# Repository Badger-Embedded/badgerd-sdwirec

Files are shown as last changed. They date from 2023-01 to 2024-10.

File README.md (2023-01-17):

# Badgerd SDWireC
[SDWireC](https://badgerd.nl/sdwirec) is a yet another implementation of SDWire of Tizen. In our design we used USB-C interface to interact with the host device or in other words Test Server(TS).

In **sdwirec-hw** folder, you can find the KiCAD project files of SDWireC, hardware design mostly based on Tizen but we changed some of the components since they are out of stock today.

In **sdwirec-sw** folder, you will find the clone of https://git.tizen.org/cgit/tools/testlab/sd-mux which has the software that you need to interact with SDWireC.

## Please follow the instructions in [Quick Start Guide](https://badgerd.nl/sdwirec/#quick-start) to give SDWireC a kickstart!

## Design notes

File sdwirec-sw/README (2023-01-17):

sd-mux stands for Secure Digital Multiplexer.

This is SD card switcher (multiplexer) designed to help automatic testing.

This project is sd-mux controller - binary for controlling sd-mux device.

Requirements:
  1. libftdi1 1.4 - development library
  2. popt - development library
  3. cmake - binary tool

Build:
 - enter into project directory
 - create 'build' directory
 - enter into "build" directory
 - run 'cmake ..'
 - run 'make'

Install:
 - enter into 'build' directory
 - run 'sudo make install' to install binary into '/usr/local/bin' (the default one) directory

Note:
If you want to install files into different directory then add argument to cmake command:
 cmake -DCMAKE_INSTALL_PREFIX=/usr ..
Then again run:
 make
 make install

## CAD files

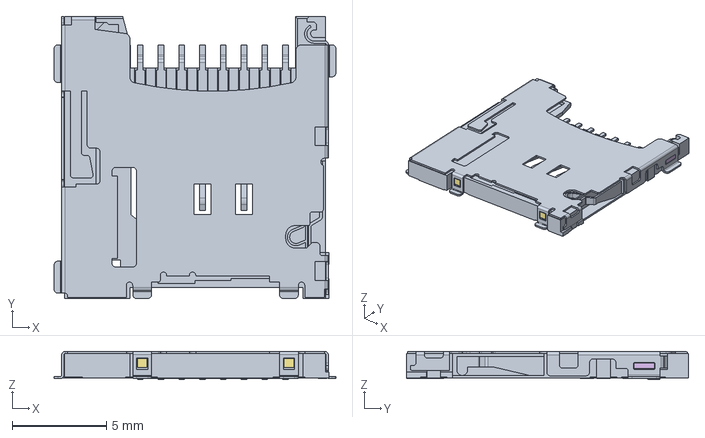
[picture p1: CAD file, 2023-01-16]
sdwirec-hw/components/503182-1852.stp
14.9 x 14.9 x 1.50 mm

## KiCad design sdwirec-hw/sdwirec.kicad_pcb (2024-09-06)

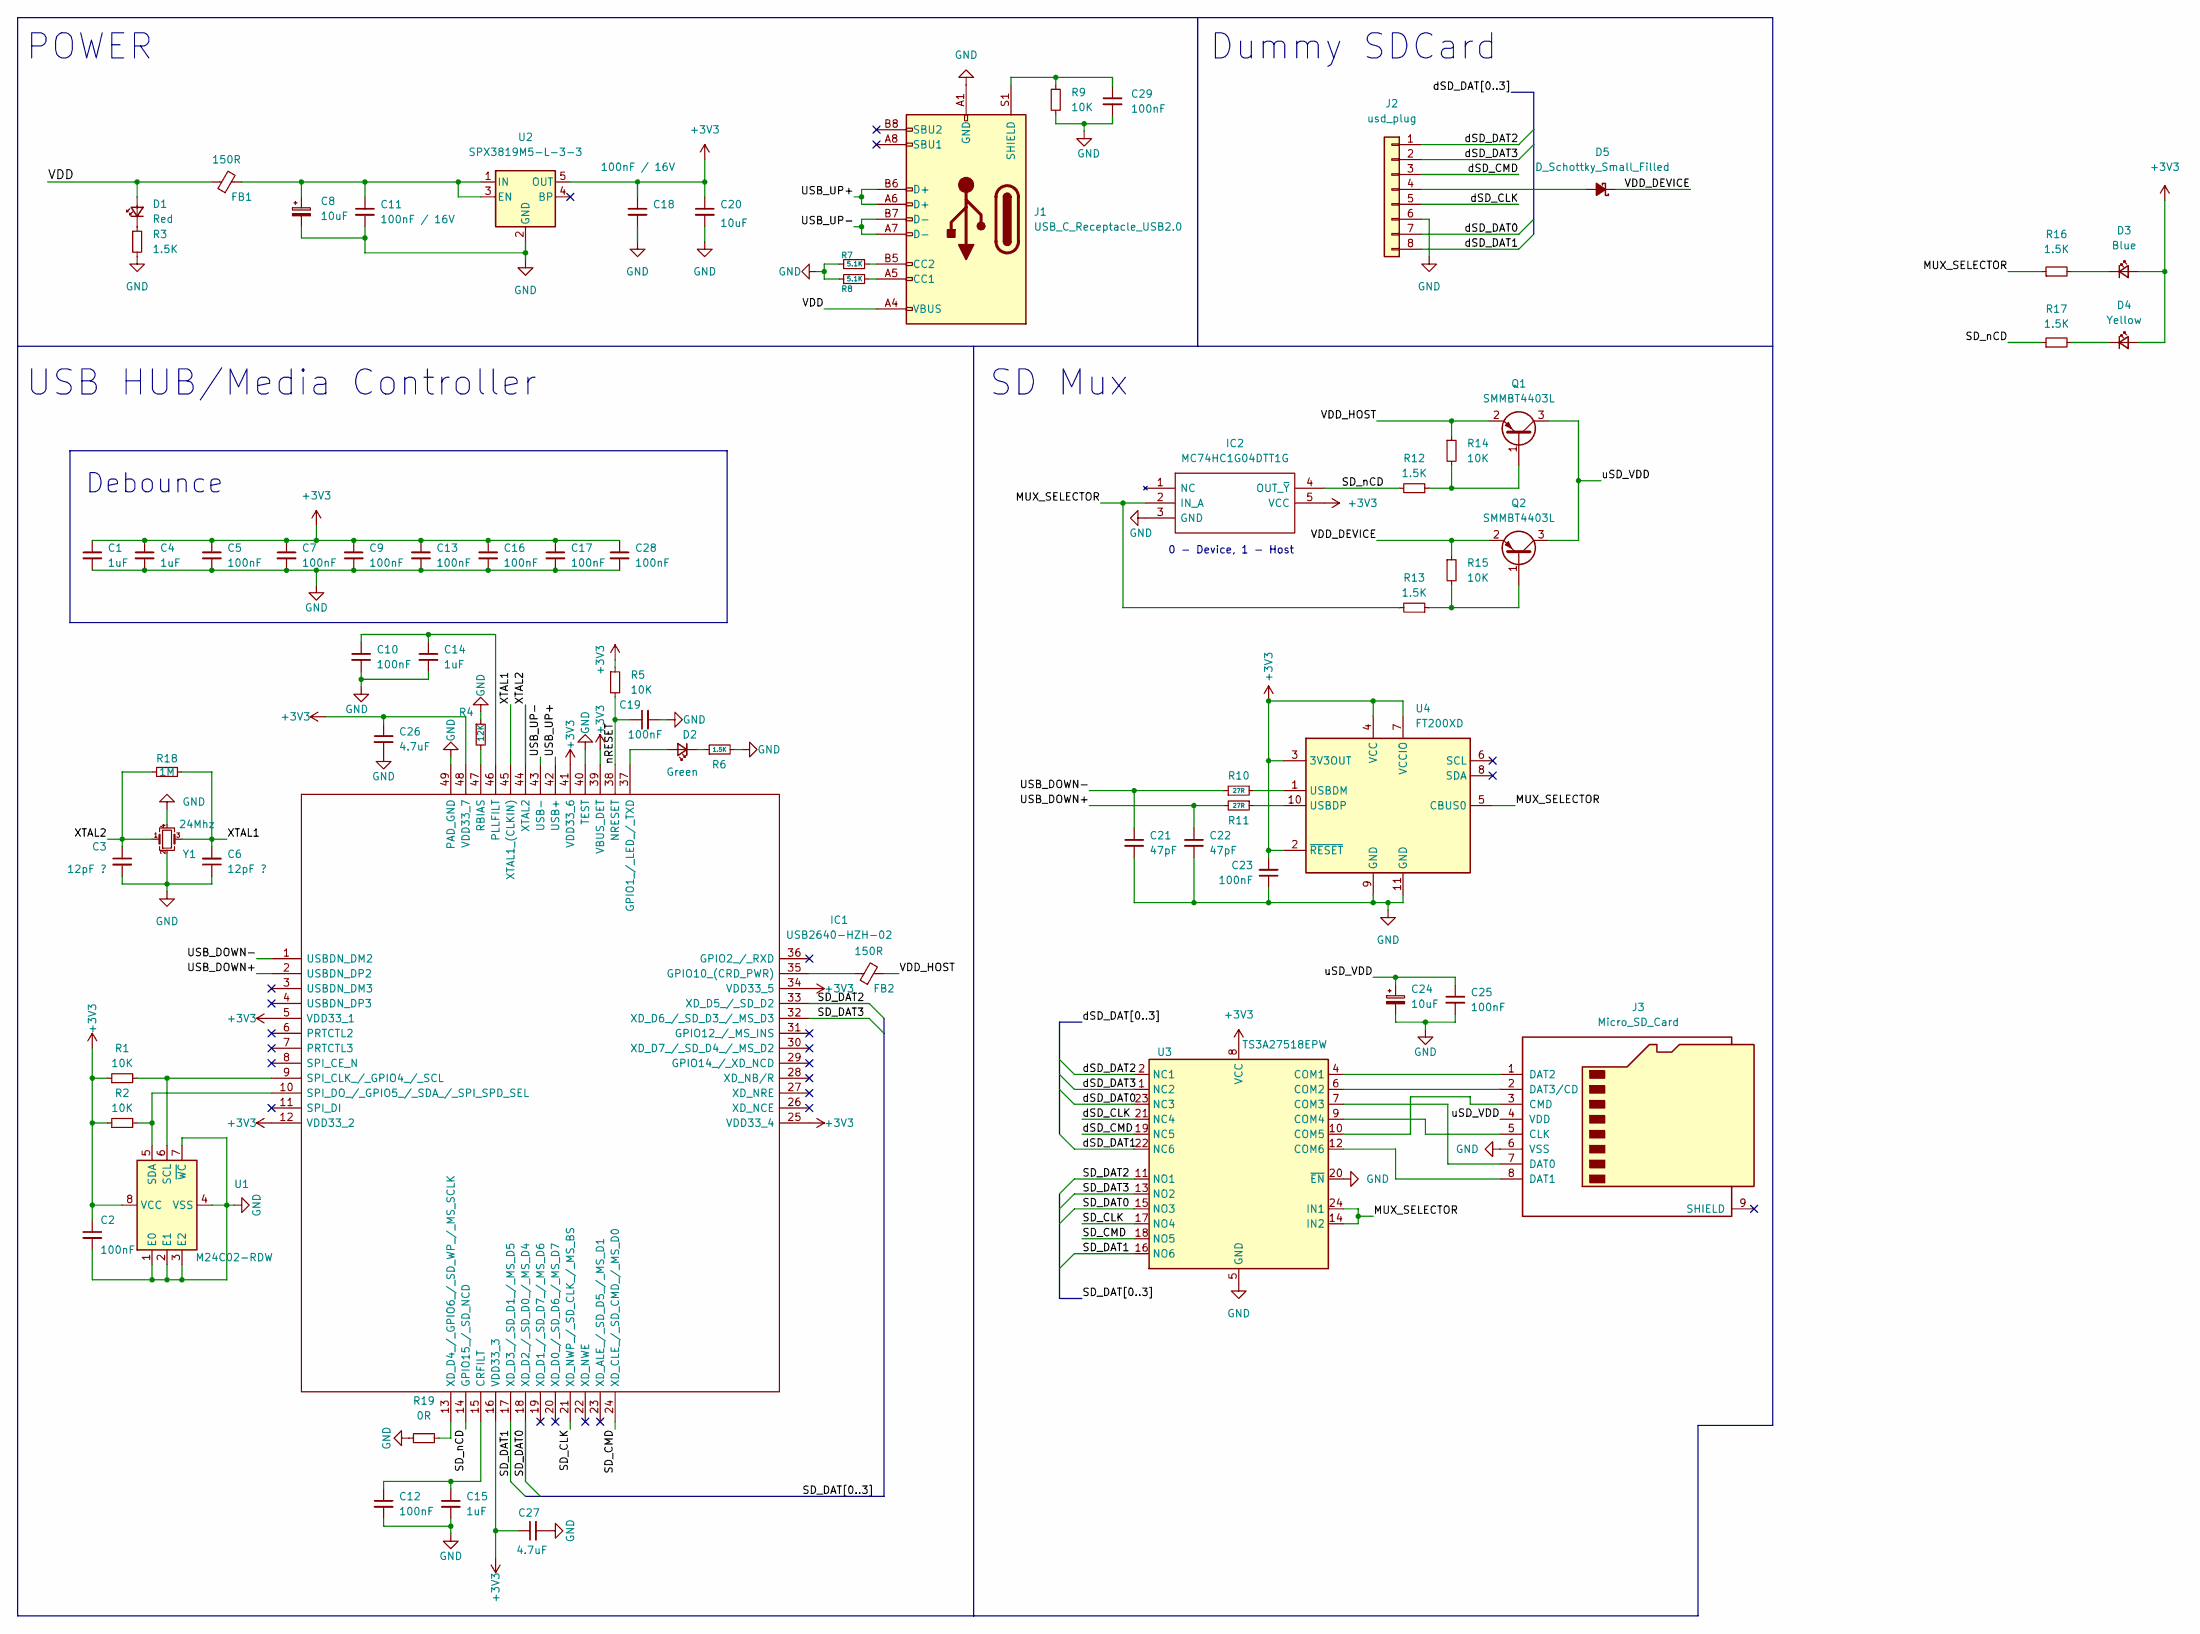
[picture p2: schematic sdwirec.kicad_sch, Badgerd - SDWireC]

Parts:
C1, C4, C14, C15: 1uF; C_0603_1608Metric; JLC 0603
C2, C5, C7, C9, C10, C12, C13, C16, C17, C19, C23, C25, C28: 100nF; C_0402_1005Metric; JLC 0402
C3, C6: 12pF ?; C_0402_1005Metric; JLC 0402
C8, C24: 10uF; CP_EIA-3216-18_Kemet-A; JLC CASE-A-3216
C11, C18: 100nF / 16V; C_0402_1005Metric; JLC 0402
C20: 10uF; C_0603_1608Metric; JLC 0603
C21, C22: 47pF; C_0402_1005Metric; JLC 0402
C26, C27: 4.7uF; C_0603_1608Metric; JLC 0603
C29: 100nF; C_0402_1005Metric
D1: Red; LED_0402_1005Metric; JLC 0402
D2: Green; LED_0402_1005Metric; JLC 0402
D3: Blue; LED_0402_1005Metric; JLC 0402
D4: Yellow; LED_0402_1005Metric; JLC 0402
D5: D_Schottky_Small_Filled; D_0402_1005Metric; LCSC Part C2837790
FB1, FB2: 150R; D_0603_1608Metric; JLC 0603
IC1: USB2640-HZH-02; QFN50P700X700X100-49N-D; Mouser Part Number 886-USB2640-HZH-02
IC2: MC74HC1G04DTT1G; SOT95P275X110-5N; Mouser Part Number 863-MC74HC1G04DTT1G
J1: USB_C_Receptacle_USB2.0; USB_C_Receptacle_GCT_USB4105-xx-A_16P_TopMnt_Horizontal; JLC SMD
J2: usd_plug; usd
J3: Micro_SD_Card; 5031821852; LCSC Part C587953
Q1, Q2: SMMBT4403L; SOT-23-3; JLC SOT-23-3
R1, R2, R5, R9, R14, R15: 10K; R_0402_1005Metric; JLC 0402
R3, R6, R12, R13, R16, R17: 1.5K; R_0402_1005Metric; JLC 0402
R4: 12K; R_0402_1005Metric; JLC 0402
R7, R8: 5.1K; R_0402_1005Metric; LCSC Part C25905
R10, R11: 27R; R_0402_1005Metric; JLC 0402
R18: 1M; R_0402_1005Metric
R19: 0R; R_0402_1005Metric; JLC 0402
U1: M24C02-RDW; TSSOP-8_4.4x3mm_P0.65mm; JLC TSSOP-8-3.0mm
U2: SPX3819M5-L-3-3; SOT-23-5; JLC SOT-23-5
U3: TS3A27518EPW; TSSOP-24_4.4x7.8mm_P0.65mm; JLC TSSOP-24
U4: FT200XD; DFN-10-1EP_3x3mm_P0.5mm_EP1.55x2.48mm; JLC DFN-10-EP(3x3)
Y1: 24Mhz; Crystal_SMD_3225-4Pin_3.2x2.5mm; JLC SMD3225-4P

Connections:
+3V3: C1.1, C2.1, C4.1, C5.1, C7.1, C9.1, C13.1, C16.1, C17.1, C18.1, C20.1, C23.2, C26.1, C27.1, C28.1, D3.2 (A), D4.2 (A), IC1.5 (VDD33_1), IC1.12 (VDD33_2), IC1.16 (VDD33_3), IC1.25 (VDD33_4), IC1.34 (VDD33_5), IC1.39 (VBUS_DET), IC1.41 (VDD33_6), IC1.48 (VDD33_7), IC2.5 (VCC), R1.1, R2.1, R5.1, U1.8 (VCC), U2.5 (OUT), U3.8 (VCC), U4.2 (~RESET), U4.3 (3V3OUT), U4.4 (VCC), U4.7 (VCCIO)
/MUX_SELECTOR: IC2.2 (IN_A), R13.2, R16.1, U3.14 (IN2), U3.24 (IN1), U4.5 (CBUS0)
/SD_CLK: IC1.21 (XD_NWP_/_SD_CLK_/_MS_BS), U3.17 (NO4)
/SD_CMD: IC1.24 (XD_CLE_/_SD_CMD_/_MS_D0), U3.18 (NO5)
/SD_DAT0: IC1.18 (XD_D2_/_SD_D0_/_MS_D4), U3.15 (NO3)
/SD_DAT1: IC1.17 (XD_D3_/_SD_D1_/_MS_D5), U3.16 (NO6)
/SD_DAT2: IC1.33 (XD_D5_/_SD_D2), U3.11 (NO1)
/SD_DAT3: IC1.32 (XD_D6_/_SD_D3_/_MS_D3), U3.13 (NO2)
/SD_nCD: IC1.14 (GPIO15_/_SD_NCD), IC2.4 (OUT_~Y), R12.2, R17.1
/USB_DOWN+: C22.1, IC1.2 (USBDN_DP2), R11.2
/USB_DOWN-: C21.1, IC1.1 (USBDN_DM2), R10.1
/USB_UP+: IC1.42 (USB+), J1.A6 (D+), J1.B6 (D+)
/USB_UP-: IC1.43 (USB-), J1.A7 (D-), J1.B7 (D-)
/VDD: D1.2 (A), FB1.1, J1.A4 (VBUS), J1.A9 (VBUS), J1.B4 (VBUS), J1.B9 (VBUS)
/VDD_DEVICE: D5.1 (K), Q2.2 (E), R15.1
/VDD_HOST: FB2.2, Q1.2 (E), R14.1
/XTAL1: C6.2, IC1.45 (XTAL1_(CLKIN)), R18.2, Y1.3
/XTAL2: C3.1, IC1.44 (XTAL2), R18.1, Y1.1
/dSD_CLK: J2.5, U3.21 (NC4)
/dSD_CMD: J2.3, U3.19 (NC5)
/dSD_DAT0: J2.7, U3.23 (NC3)
/dSD_DAT1: J2.8, U3.22 (NC6)
/dSD_DAT2: J2.1, U3.2 (NC1)
/dSD_DAT3: J2.2, U3.1 (NC2)
/nRESET: C19.1, IC1.38 (NRESET), R5.2
/uSD_VDD: C24.1, C25.1, J3.4 (VDD), Q1.3 (C), Q2.3 (C)
GND: C1.2, C2.2, C3.2, C4.2, C5.2, C6.1, C7.2, C8.2, C9.2, C10.2, C11.2, C12.2, C13.2, C14.2, C15.2, C16.2, C17.2, C18.2, C19.2, C20.2, C21.2, C22.2, C23.1, C24.2, C25.2, C26.2, C27.2, C28.2, C29.2, IC1.40 (TEST), IC1.49 (PAD_GND), IC2.3 (GND), J1.A1 (GND), J1.A12 (GND), J1.B1 (GND), J1.B12 (GND), J2.6, J3.6 (VSS), R3.2, R4.1, R6.2, R7.1, R8.1, R9.2, R19.1, U1.1 (E0), U1.2 (E1), U1.3 (E2), U1.4 (VSS), U1.7 (~WC), U2.2 (GND), U3.5 (GND), U3.20 (~EN), U4.9 (GND), U4.11 (GND), Y1.2, Y1.4
unnamed: C10.1, C14.1, IC1.46 (PLLFILT)
unnamed: C8.1, C11.1, FB1.2, U2.1 (IN), U2.3 (EN)
unnamed: C12.1, C15.1, IC1.15 (CRFILT)
unnamed: C29.1, J1.S1 (SHIELD), R9.1
unnamed: D1.1 (K), R3.1
unnamed: D2.1 (K), R6.1
unnamed: D2.2 (A), IC1.37 (GPIO1_/_LED_/_TXD)
unnamed: D3.1 (K), R16.2
unnamed: D4.1 (K), R17.2
unnamed: FB2.1, IC1.35 (GPIO10_(CRD_PWR))
unnamed: IC1.9 (SPI_CLK_/_GPIO4_/_SCL), R1.2, U1.6 (SCL)
unnamed: IC1.10 (SPI_DO_/_GPIO5_/_SDA_/_SPI_SPD_SEL), R2.2, U1.5 (SDA)
unnamed: IC1.13 (XD_D4_/_GPIO6_/_SD_WP_/_MS_SCLK), R19.2
unnamed: IC1.47 (RBIAS), R4.2
unnamed: J1.A5 (CC1), R8.2
unnamed: J1.B5 (CC2), R7.2
unnamed: D5.2 (A), J2.4
unnamed: J3.1 (DAT2), U3.4 (COM1)
unnamed: J3.2 (DAT3/CD), U3.6 (COM2)
unnamed: J3.3 (CMD), U3.10 (COM5)
unnamed: J3.5 (CLK), U3.9 (COM4)
unnamed: J3.7 (DAT0), U3.7 (COM3)
unnamed: J3.8 (DAT1), U3.12 (COM6)
unnamed: Q1.1 (B), R12.1, R14.2
unnamed: Q2.1 (B), R13.1, R15.2
unnamed: R10.2, U4.1 (USBDM)
unnamed: R11.1, U4.10 (USBDP)

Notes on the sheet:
0 - Device, 1 - Host
POWER
SD Mux
USB HUB/Media Controller
Dummy SDCard
Debounce

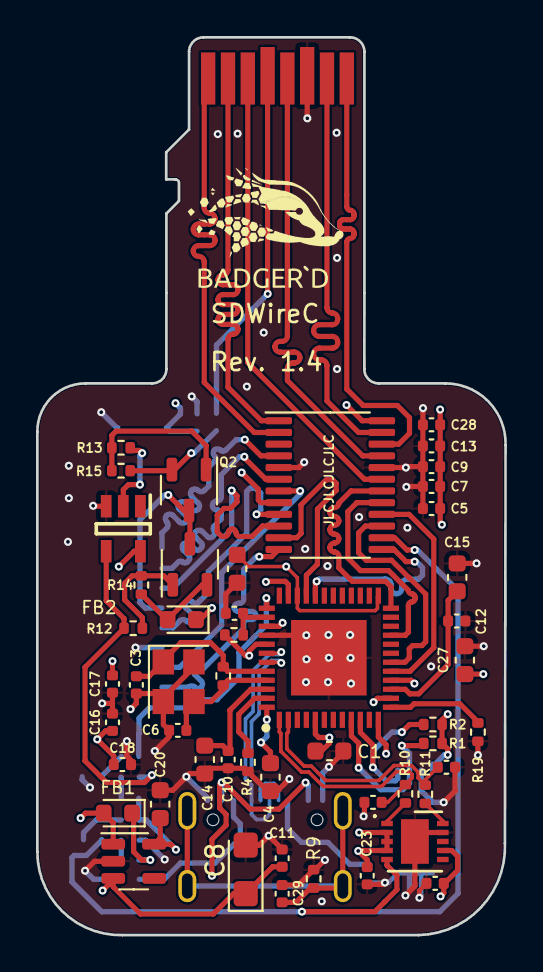
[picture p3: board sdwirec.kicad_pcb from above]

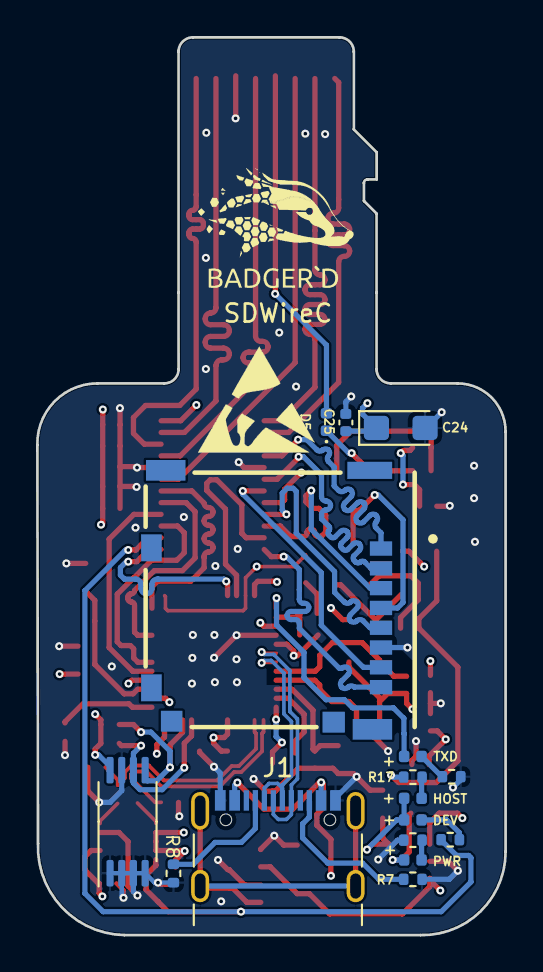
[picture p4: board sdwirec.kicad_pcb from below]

Board: 4 copper layers, 26.0 x 49.9 mm, 67 parts (16 on the bottom side), 54 nets.

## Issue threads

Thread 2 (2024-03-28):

Hardware Feature Request: USB 3 chip

moqmar, 2024-03-28:
It would be great to get faster speeds on the USB side of the SDWireC. Is this planned as a future update?

talhaHavadar, 2024-03-28:
Hi @moqmar , we are currently working on a design of a new version that utilizes GL3231S which is a USB3 UHS-II capable media chip.

This will of course will require some changes in regard of shape of the board. We are aiming to release the new version by the end of this summer at the latest.

Please raise your concerns if you have any or maybe features that you would like to see added. Thank you for your interest on the project

moqmar, 2024-09-10:
Thank you for the quick reply back in March, I'm really looking forward to the new version! Is the release still planned for the next months? We are considering whether to wait to order a few of the new version.

talhaHavadar, 2024-09-10:
@moqmar still not ready for production we are expecting to have prototype run number 3 to arrive this friday, we need to do the tests and then according to results we may need another prototyping run so I cant really promise a date for it

moqmar, 2024-09-11:
Sounds good, then I'll be waiting for it 😉

talhaHavadar, 2024-09-29:
@moqmar we are in process of implementing firmware for the SDWire Gen2 but I would like to send you a sample when it is ready to be used. Can you please reach out to us from [this](mailto:info@badgerd.nl) email?

ohault, 2025-03-20:
I would be interested too.

zombie343, 2025-04-29:
Same! Also interested!

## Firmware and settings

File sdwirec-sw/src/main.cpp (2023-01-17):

/*
 *  Copyright (c) 2016 -2018 Samsung Electronics Co., Ltd All Rights Reserved
 *
 *  Licensed under the Apache License, Version 2.0 (the "License");
 *  you may not use this file except in compliance with the License.
 *  You may obtain a copy of the License at
 *
 *      http://www.apache.org/licenses/LICENSE-2.0
 *
 *  Unless required by applicable law or agreed to in writing, software
 *  distributed under the License is distributed on an "AS IS" BASIS,
 *  WITHOUT WARRANTIES OR CONDITIONS OF ANY KIND, either express or implied.
 *  See the License for the specific language governing permissions and
 *  limitations under the License
 */
/**
 * @file        src/main.cpp
 * @author      Adam Malinowski <a.malinowsk2@partner.samsung.com>
 * @brief       Main sd-mux-ctrl file
 */

#include <popt.h>
#include <stdio.h>
#include <stdlib.h>
#include <string.h>
#include <unistd.h>

#include <libftdi1/ftdi.h>

#define PRODUCT 0x6001
#define SAMSUNG_VENDOR 0x04e8

// SDMUX specific definitions
#define SOCKET_SEL      (0x01 << 0x00)
#define USB_SEL         (0x01 << 0x03)
#define POWER_SW_OFF    (0x01 << 0x02)
#define POWER_SW_ON     (0x01 << 0x04)
#define DYPER1          (0x01 << 0x05)
#define DYPER2          (0x01 << 0x06)

// USBMUX specific definitions
#define UM_SOCKET_SEL	(0x01 << 0x00)
#define UM_DEVICE_PWR	(0x01 << 0x01)
#define UM_DUT_LED		(0x01 << 0x02)
#define UM_GP_LED		(0x01 << 0x03)


#define DELAY_100MS     100000
#define DELAY_500MS     500000

#define CCDT_SDMUX_STR  "sd-mux"
#define CCDT_SDWIRE_STR "sd-wire"
#define CCDT_USBMUX_STR "usb-mux"

#define STRING_SIZE     128

enum CCCommand {
    CCC_List,
    CCC_DUT,
    CCC_TS,
    CCC_Tick,
    CCC_Pins,
    CCC_Info,
    CCC_ShowSerial,
    CCC_SetSerial,
    CCC_Init,
    CCC_Status,
    CCC_DyPer1,
    CCC_DyPer2,
    CCC_None
};

enum Target {
    T_DUT,
    T_TS
};

enum CCDeviceType {
    CCDT_SDMUX,
    CCDT_SDWIRE,
	CCDT_USBMUX,
    CCDT_MAX
};

enum CCFeature {
    CCF_SDMUX,
    CCF_POWERSWITCH,
    CCF_USBMUX,
    CCF_DYPERS,
    CCF_MAX
};

enum CCOption {
    CCO_DeviceId,
    CCO_DeviceSerial,
    CCO_TickTime,
    CCO_BitsInvert,
    CCO_Vendor,
    CCO_Product,
    CCO_DyPer,
    CCO_DeviceType,
    CCO_MAX
};

union CCOptionValue {
    int argn;
    char *args;
};

int doPower(bool off, bool on, CCOptionValue options[]);
int selectTarget(Target target, CCOptionValue options[]);

CCDeviceType getDeviceTypeFromString(char *deviceTypeStr) {
    if (strcmp(CCDT_SDMUX_STR, deviceTypeStr) == 0) {
        return CCDT_SDMUX;
    }

    if (strcmp(CCDT_SDWIRE_STR, deviceTypeStr) == 0) {
        return CCDT_SDWIRE;
    }

    if (strcmp(CCDT_USBMUX_STR, deviceTypeStr) == 0) {
        return CCDT_USBMUX;
    }

    return CCDT_MAX;
}

bool hasFeature(CCDeviceType deviceType, CCFeature feature) {
    static const bool featureMatrix[CCDT_MAX][CCF_MAX] = {
            {true, true, true, true},           // SD-MUX features
            {true, false, false, false},        // SDWire features
			{false, false, true, false},        // SDWire features
    };

    if (deviceType >= CCDT_MAX || feature >= CCF_MAX)
        return false;

    return featureMatrix[deviceType][feature];
}

int listDevices(CCOptionValue options[]) {
    int fret, i;
    struct ftdi_context *ftdi;
    struct ftdi_device_list *devlist, *curdev;
    char manufacturer[STRING_SIZE + 1], description[STRING_SIZE + 1], serial[STRING_SIZE + 1];
    int retval = EXIT_SUCCESS;

    if ((ftdi = ftdi_new()) == 0) {
        fprintf(stderr, "ftdi_new failed\n");
        return EXIT_FAILURE;
    }

    if ((fret = ftdi_usb_find_all(ftdi, &devlist, options[CCO_Vendor].argn, options[CCO_Product].argn)) < 0) {
        fprintf(stderr, "ftdi_usb_find_all failed: %d (%s)\n", fret, ftdi_get_error_string(ftdi));
        ftdi_free(ftdi);
        return EXIT_FAILURE;
    }

    if (options[CCO_DeviceId].argn == -1) {
        printf("Number of FTDI devices found: %d\n", fret);
    }

    i = 0;
    for (curdev = devlist; curdev != NULL; i++) {
        if (options[CCO_DeviceId].argn == -1 || options[CCO_DeviceId].argn == i) {
            if ((fret = ftdi_usb_get_strings(ftdi, curdev->dev, manufacturer, STRING_SIZE, description, STRING_SIZE,
                    serial, STRING_SIZE)) < 0) {
                fprintf(stderr, "ftdi_usb_get_strings failed: %d (%s)\n", fret, ftdi_get_error_string(ftdi));
                retval = EXIT_FAILURE;
                goto finish_him;
            }
            if (options[CCO_DeviceId].argn == -1) {
                printf("Dev: %d, Manufacturer: %s, Serial: %s, Description: %s\n", i,
                       manufacturer, serial, description);
            } else {
                printf("%s", serial);
            }
        }
        curdev = curdev->next;
    }

finish_him:
    ftdi_list_free(&devlist);
    ftdi_free(ftdi);

    return retval;
}

struct ftdi_context* openDevice(CCOptionValue options[], CCDeviceType *deviceType) {
    struct ftdi_context *ftdi = NULL;
    int fret;
    char product[STRING_SIZE + 1];
    CCDeviceType tmpDeviceType;

    if ((options[CCO_DeviceSerial].args == NULL) && (options[CCO_DeviceId].argn < 0)) {
        fprintf(stderr, "No serial number or device id provided!\n");
        return NULL;
    }

    if ((ftdi = ftdi_new()) == 0) {
        fprintf(stderr, "ftdi_new failed\n");
        return NULL;
    }

    if (options[CCO_DeviceSerial].args != NULL) {
        fret = ftdi_usb_open_desc_index(ftdi, options[CCO_Vendor].argn, options[CCO_Product].argn, NULL, options[CCO_DeviceSerial].args, 0);
    } else {
        fret = ftdi_usb_open_desc_index(ftdi, options[CCO_Vendor].argn, options[CCO_Product].argn, NULL, NULL, options[CCO_DeviceId].argn);
    }
    if (fret < 0) {
        fprintf(stderr, "Unable to open ftdi device: %d (%s)\n", fret, ftdi_get_error_string(ftdi));
        goto error;
    }

    fret = ftdi_read_eeprom(ftdi);
    if (fret < 0) {
        fprintf(stderr, "Unable to read ftdi eeprom: %d (%s)\n", fret, ftdi_get_error_string(ftdi));
        goto error;
    }

    fret = ftdi_eeprom_decode(ftdi, 0);
    if (fret < 0) {
        fprintf(stderr, "Unable to decode ftdi eeprom: %d (%s)\n", fret, ftdi_get_error_string(ftdi));
        goto error;
    }

    if (deviceType != NULL) {
        ftdi_eeprom_get_strings(ftdi, NULL, 0, product, sizeof(product), NULL, 0);
        tmpDeviceType = getDeviceTypeFromString(product);
        if (tmpDeviceType == CCDT_MAX) {
            fprintf(stderr, "Invalid device type. Device probably not configured!\n");
            goto error;
        }
        *deviceType = tmpDeviceType;
    }

    return ftdi;

error:
    ftdi_usb_close(ftdi);
    ftdi_free(ftdi);

    return NULL;
}

int showInfo(CCOptionValue options[]) {
    struct ftdi_context *ftdi;
    int fret, ret = EXIT_SUCCESS;

    ftdi = openDevice(options, NULL);
    if (ftdi == NULL) {
        return EXIT_FAILURE;
    }

    fret = ftdi_eeprom_decode(ftdi, 1);
    if (fret < 0) {
        fprintf(stderr, "Unable to decode ftdi eeprom: %d (%s)\n", fret, ftdi_get_error_string(ftdi));
        ret = EXIT_FAILURE;
        ftdi_usb_close(ftdi);
        ftdi_free(ftdi);
    }

    return ret;
}

int doInit(CCOptionValue options[]) {
    if (doPower(true, false, options) != EXIT_SUCCESS) {
        return EXIT_FAILURE;
    }

    if (selectTarget(T_TS, options) != EXIT_SUCCESS) {
        return EXIT_FAILURE;
    }

    return EXIT_SUCCESS;
}

int setSerial(char *serialNumber, CCOptionValue options[]) {
    struct ftdi_context *ftdi;
    int f, ret = EXIT_FAILURE;
    char *type = options[CCO_DeviceType].args;

    if (!type) {
        fprintf(stderr, "Device type not specified\n");
        return EXIT_FAILURE;
    }

    ftdi = openDevice(options, NULL);
    if (ftdi == NULL) {
        return EXIT_FAILURE;
    }

    f = ftdi_eeprom_initdefaults(ftdi, (char *)"SRPOL", type, serialNumber);
    if (f < 0) {
        fprintf(stderr, "Unable to set eeprom strings: %d (%s)\n", f, ftdi_get_error_string(ftdi));
        goto finish_him;
    }

    f = ftdi_set_eeprom_value(ftdi, VENDOR_ID, SAMSUNG_VENDOR);
    if (f < 0) {
        fprintf(stderr, "Unable to set eeprom strings: %d (%s)\n", f, ftdi_get_error_string(ftdi));
        goto finish_him;
    }

    f = ftdi_set_eeprom_value(ftdi, PRODUCT_ID, PRODUCT);
    if (f < 0) {
        fprintf(stderr, "Unable to set eeprom strings: %d (%s)\n", f, ftdi_get_error_string(ftdi));
        goto finish_him;
    }

    if (getDeviceTypeFromString(type) == CCDT_SDWIRE) {
        f = ftdi_set_eeprom_value(ftdi, CBUS_FUNCTION_0, CBUSH_IOMODE);
        if (f < 0) {
            fprintf(stderr, "Unable to set eeprom value: %d (%s)\n", f, ftdi_get_error_string(ftdi));
            goto finish_him;
        }
    }

    if (getDeviceTypeFromString(type) == CCDT_USBMUX) {
        f = ftdi_set_eeprom_value(ftdi, CBUS_FUNCTION_0, CBUSH_IOMODE);
        if (f < 0) {
            fprintf(stderr, "Unable to set eeprom value: %d (%s)\n", f, ftdi_get_error_string(ftdi));
            goto finish_him;
        }
        f = ftdi_set_eeprom_value(ftdi, CBUS_FUNCTION_1, CBUSH_IOMODE);
        if (f < 0) {
            fprintf(stderr, "Unable to set eeprom value: %d (%s)\n", f, ftdi_get_error_string(ftdi));
            goto finish_him;
        }
        f = ftdi_set_eeprom_value(ftdi, CBUS_FUNCTION_2, CBUSH_IOMODE);
        if (f < 0) {
            fprintf(stderr, "Unable to set eeprom value: %d (%s)\n", f, ftdi_get_error_string(ftdi));
            goto finish_him;
        }
        f = ftdi_set_eeprom_value(ftdi, CBUS_FUNCTION_3, CBUSH_IOMODE);
        if (f < 0) {
            fprintf(stderr, "Unable to set eeprom value: %d (%s)\n", f, ftdi_get_error_string(ftdi));
            goto finish_him;
        }
    }

    f = ftdi_eeprom_build(ftdi);
    if (f < 0) {
        fprintf(stderr, "Unable to build eeprom: %d (%s)\n", f, ftdi_get_error_string(ftdi));
        goto finish_him;
    }

    f = ftdi_write_eeprom(ftdi);
    if (f < 0) {
        fprintf(stderr, "Unable to write eeprom into device: %d (%s)\n", f, ftdi_get_error_string(ftdi));
        goto finish_him;
    }

    ret = EXIT_SUCCESS;

finish_him:
    ftdi_usb_close(ftdi);
    ftdi_free(ftdi);

    return ret;
}

int writePins(struct ftdi_context *ftdi, unsigned char pins) {
    int f = ftdi_write_data(ftdi, &pins, 1);
    if (f < 0) {
        fprintf(stderr,"write failed for 0x%x, error %d (%s)\n", pins, f, ftdi_get_error_string(ftdi));
        return EXIT_FAILURE;
    }
    return EXIT_SUCCESS;
}

struct ftdi_context* prepareDevice(CCOptionValue options[], unsigned char *pins, CCDeviceType *deviceType) {
    struct ftdi_context *ftdi;
    int f;

    ftdi = openDevice(options, deviceType);
    if (ftdi == NULL) {
        return NULL;
    }

    if (*deviceType == CCDT_SDWIRE || *deviceType == CCDT_USBMUX) {
        return ftdi; // None of the following steps need to be performed for this type of device.
    }

    f = ftdi_set_bitmode(ftdi, 0xFF, BITMODE_BITBANG);
    if (f < 0) {
        fprintf(stderr, "Unable to enable bitbang mode: %d (%s)\n", f, ftdi_get_error_string(ftdi));
        ftdi_usb_close(ftdi);
        ftdi_free(ftdi);
        return NULL;
    }

    if (pins != NULL) {
        f = ftdi_read_data(ftdi, pins, 1);
        if (f < 0) {
            fprintf(stderr,"read failed, error %d (%s)\n", f, ftdi_get_error_string(ftdi));
            ftdi_usb_close(ftdi);
            ftdi_free(ftdi);
            return NULL;
        }
    }

    return ftdi;
}

int powerOff(struct ftdi_context *ftdi, unsigned char *pins) {
    // Turn on the coil
    *pins |= POWER_SW_ON;
    *pins &= ~(POWER_SW_OFF);
    if (writePins(ftdi, *pins) != EXIT_SUCCESS)
        return EXIT_FAILURE;

    // Wait for 100ms
    usleep(DELAY_100MS);

    // Turn off the coil
    *pins |= POWER_SW_OFF;
    if (writePins(ftdi, *pins) != EXIT_SUCCESS)
        return EXIT_FAILURE;

    return EXIT_SUCCESS;
}

int powerOn(struct ftdi_context *ftdi, unsigned char *pins) {
    // Turn on the coil
    *pins |= POWER_SW_OFF;
    *pins &= ~(POWER_SW_ON);
    if (writePins(ftdi, *pins) != EXIT_SUCCESS)
        return EXIT_FAILURE;

    // Wait for 100ms
    usleep(DELAY_100MS);

    // Turn off the coil
    *pins |= POWER_SW_ON;
    if (writePins(ftdi, *pins) != EXIT_SUCCESS)
        return EXIT_FAILURE;

    return EXIT_SUCCESS;
}

int doPower(bool off, bool on, CCOptionValue options[]) {
    unsigned char pins;
    CCDeviceType deviceType;
    int ret = EXIT_SUCCESS;

    int period = 1000;
    if (options[CCO_TickTime].argn > 0) {
        period = options[CCO_TickTime].argn;
    }

    struct ftdi_context *ftdi = prepareDevice(options, &pins, &deviceType);
    if (ftdi == NULL)
        return EXIT_FAILURE;

    if (!hasFeature(deviceType, CCF_POWERSWITCH)) {
        fprintf(stderr,"Power switching is not available on this device.\n");
        ret = EXIT_FAILURE;
        goto finish_him;
    }

    ret = powerOff(ftdi, &pins);
    if (off && (ret != EXIT_SUCCESS)) {
        ret = EXIT_FAILURE;
        goto finish_him;
    }

    // Wait for specified period in ms
    usleep(period * 1000);

    ret = powerOn(ftdi, &pins);
    if (on && (ret != EXIT_SUCCESS)) {
        ret = EXIT_FAILURE;
        goto finish_him;
    }

finish_him:
    ftdi_usb_close(ftdi);
    ftdi_free(ftdi);

    return ret;
}

int selectTarget(Target target, CCOptionValue options[]) {
    unsigned char pins;
    CCDeviceType deviceType;
    int ret = EXIT_SUCCESS;

    struct ftdi_context *ftdi = prepareDevice(options, &pins, &deviceType);
    if (ftdi == NULL)
        return EXIT_FAILURE;

    if (deviceType == CCDT_SDWIRE) {
        unsigned char pinState = 0x00;
        pinState |= 0xF0; // Upper half of the byte sets all pins to output (SDWire has only one bit - 0)
        pinState |= target == T_DUT ? 0x00 : 0x01; // Lower half of the byte sets state of output pins.
                                                   // In this particular case we care only of bit 0.
        ret |= ftdi_set_bitmode(ftdi, pinState, BITMODE_CBUS);
        goto finish_him;
    }

    if (deviceType == CCDT_USBMUX) {
        unsigned char pinState = 0xF0;

        if (target == T_DUT) {
            pinState &= ~UM_DEVICE_PWR;
            ret |= ftdi_set_bitmode(ftdi, pinState, BITMODE_CBUS);
            usleep(DELAY_500MS);
            pinState |= UM_DEVICE_PWR;
            ret |= ftdi_set_bitmode(ftdi, pinState, BITMODE_CBUS);
            usleep(DELAY_100MS);
            pinState |= UM_DUT_LED;
            pinState &= ~UM_SOCKET_SEL;
            pinState &= ~UM_GP_LED;
            ret |= ftdi_set_bitmode(ftdi, pinState, BITMODE_CBUS);
        } else {
            pinState &= ~UM_DUT_LED;
            pinState &= ~UM_DEVICE_PWR;
            ret |= ftdi_set_bitmode(ftdi, pinState, BITMODE_CBUS);
            usleep(DELAY_500MS);
            pinState |= UM_DEVICE_PWR;
            ret |= ftdi_set_bitmode(ftdi, pinState, BITMODE_CBUS);
            usleep(DELAY_100MS);
            pinState |= UM_SOCKET_SEL;
            pinState |= UM_GP_LED;
            ret |= ftdi_set_bitmode(ftdi, pinState, BITMODE_CBUS);
        }

        goto finish_him;
    }

    // Currently only old SD-MUX is the other device so do the job in its style.
    if (target == T_DUT) {
        pins &= ~(USB_SEL);
        pins &= ~(SOCKET_SEL);
        if (powerOn(ftdi, &pins) != EXIT_SUCCESS) {  // Also selects USB and SD
            ret = EXIT_FAILURE;
            goto finish_him;
        }
    } else {
        pins |= USB_SEL;
        pins |= SOCKET_SEL;
        if (powerOff(ftdi, &pins) != EXIT_SUCCESS) { // Also selects USB and SD
            ret = EXIT_FAILURE;
            goto finish_him;
        }
    }

finish_him:
    ftdi_usb_close(ftdi);
    ftdi_free(ftdi);

    return ret;
}

int setPins(unsigned char pins, CCOptionValue options[]) {
    CCDeviceType deviceType;
    struct ftdi_context *ftdi = prepareDevice(options, NULL, &deviceType);
    if (ftdi == NULL)
        return EXIT_FAILURE;

    if (options[CCO_DeviceSerial].args) {
        pins = ~pins;
    }

    if (deviceType == CCDT_SDWIRE) {
        // SDWire has only one pin already controlled by selectTarget function.
        // There is no use to repeat this functionality here.
        return EXIT_FAILURE;
    }

    printf("Write data: 0x%x\n", pins);

    int ret = writePins(ftdi, pins);

    ftdi_usb_close(ftdi);
    ftdi_free(ftdi);

    return ret;
}

int showStatus(CCOptionValue options[]) {
	int ret = 0;
    unsigned char pins;
    CCDeviceType deviceType;
    struct ftdi_context *ftdi = prepareDevice(options, &pins, &deviceType);
    if (ftdi == NULL)
        return EXIT_FAILURE;


    if (deviceType == CCDT_SDWIRE) {
       if (ftdi_read_pins(ftdi, &pins) != 0) {
           fprintf(stderr, "Error reading pins state.\n");
           ret = EXIT_FAILURE;
           goto finish_him;
       }
       fprintf(stdout, "SD connected to: %s\n", pins & SOCKET_SEL ? "TS" : "DUT");
       goto finish_him;
    }

    if (deviceType == CCDT_USBMUX) {
       if (ftdi_read_pins(ftdi, &pins) != 0) {
           fprintf(stderr, "Error reading pins state.\n");
           ret = EXIT_FAILURE;
           goto finish_him;
       }

       if (pins == 0xff) {
           fprintf(stdout, "Device not initialized!\n");
           goto finish_him;
       }

       fprintf(stdout, "SD connected to: %s\n", pins & UM_SOCKET_SEL ? "TS" : "DUT");
       goto finish_him;
    }

    // Currently only old SD-MUX is the other device so do the job in its style.
    if (!((pins & POWER_SW_ON) && (pins & POWER_SW_OFF))) {
        fprintf(stdout, "Device not initialized!\n");
        goto finish_him;
    }

    fprintf(stdout, "USB connected to: %s\n", pins & USB_SEL ? "TS" : "DUT");
    fprintf(stdout, "SD connected to: %s\n", pins & SOCKET_SEL ? "TS" : "DUT");

finish_him:
    ftdi_usb_close(ftdi);
    ftdi_free(ftdi);

    return ret;
}

int setDyPer(CCCommand cmd, CCOptionValue options[]) {
    unsigned char pins;
    bool switchOn;
    CCDeviceType deviceType;
    int ret = EXIT_SUCCESS, dyper;

    struct ftdi_context *ftdi = prepareDevice(options, &pins, &deviceType);
    if (ftdi == NULL)
        return EXIT_FAILURE;

    if (!hasFeature(deviceType, CCF_DYPERS)) {
        fprintf(stderr,"DyPers are not available on this device.\n");
        return EXIT_FAILURE;
    }

    #define STRON "ON"
    #define STROFF "OFF"

    if (strcasecmp(STRON, options[CCO_DyPer].args) == 0) {
      switchOn = true;
    } else if (strcasecmp(STROFF, options[CCO_DyPer].args) == 0) {
      switchOn = false;
    } else {
      fprintf(stderr,"Invalid DyPer argument! Use \"on\" or \"off\".\n");
      goto finish_him;
    }

    dyper = cmd == CCC_DyPer1 ? DYPER1 : DYPER2;
    pins = switchOn ? pins | dyper : pins & ~dyper;

    if (writePins(ftdi, pins) != EXIT_SUCCESS)
        ret = EXIT_FAILURE;

finish_him:
    ftdi_usb_close(ftdi);
    ftdi_free(ftdi);

    return ret;
}
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
int main(int argc, const char **argv) {
    CCCommand cmd = CCC_None;
    int arg;
    char args[64];
    CCOptionValue options[CCO_MAX];
    memset(&options, 0, sizeof(options));
    options[CCO_DeviceId].argn = -1;
    options[CCO_Vendor].argn = SAMSUNG_VENDOR;
    options[CCO_Product].argn = PRODUCT;

    if (parseArguments(argc, argv, &cmd, &arg, args, sizeof(args), options) != EXIT_SUCCESS) {
        return EXIT_FAILURE;
    }

    switch (cmd) {
    case CCC_None:
        fprintf(stderr, "No command specified\n");
        return EXIT_FAILURE;
    case CCC_List:
        return listDevices(options);
    case CCC_Info:
        return showInfo(options);
    case CCC_ShowSerial:
        return listDevices(options);
    case CCC_SetSerial:
        return setSerial(args, options);
    case CCC_Init:
        return doInit(options);
    case CCC_DUT:
        return selectTarget(T_DUT, options);
    case CCC_TS:
        return selectTarget(T_TS, options);
    case CCC_Tick:
        return doPower(true, true, options);
    case CCC_Pins:
        return setPins((unsigned char)arg, options);
    case CCC_DyPer1:
    case CCC_DyPer2:
        return setDyPer(cmd, options);
    case CCC_Status:
        return showStatus(options);
    }

    return EXIT_SUCCESS;
}

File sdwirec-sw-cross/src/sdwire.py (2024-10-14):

#!/usr/bin/env python3

#
# sdwire.py - SDWire control script
#
# Copyright (c) 2024 skgleba
#
# This software may be modified and distributed under the terms
# of the MIT license.  See the LICENSE file for details.
#
# REQUIRES pyftdi, pyusb, libusb and/or WinUSB (Windows)
#

import usb.core
import usb.util
from pyftdi.ftdi import Ftdi
from pyftdi.eeprom import FtdiEeprom
import sys
import argparse

DEFAULT_PRODUCT = "sd-wire"


def list_usb_devices():  # list all USB devices
    devices = usb.core.find(find_all=True)
    if not devices:
        print("No USB devices found")
        return []

    device_list = []
    for device in devices:
        try:
            product = usb.util.get_string(device, device.iProduct)
        except Exception as e:
            product = "Unknown"

        try:
            serial = usb.util.get_string(device, device.iSerialNumber)
        except Exception as e:
            serial = "Unknown"

        device_info = f"{device.bus:03d}:{device.address:03d} | {device.idVendor:04x}:{device.idProduct:04x} | {product} | {serial}"
        device_list.append(device_info)

    return device_list


def find_usb_device(product=None, serial=None, device=None, busaddr=None):
    if device or busaddr:
        search_args = {"find_all": True}
        if device:
            vid, pid = device.split(":")
            search_args["idVendor"] = int(vid, 16)
            search_args["idProduct"] = int(pid, 16)
        if busaddr:
            bus, addr = busaddr.split(":")
            search_args["bus"] = int(bus)
            search_args["address"] = int(addr)
        devices = usb.core.find(**search_args)
    else:
        devices = usb.core.find(find_all=True)
    if not devices:
        print("No USB devices found")
        return None

    for device in devices:
        try:
            dev_product = usb.util.get_string(device, device.iProduct)
        except Exception as e:
            dev_product = "Unknown"

        try:
            dev_serial = usb.util.get_string(device, device.iSerialNumber)
        except Exception as e:
            dev_serial = "Unknown"

        if product and product != dev_product:
            continue
        if serial and serial != dev_serial:
            continue
        return device

    return None


def set_sdwire(target, product=None, serial=None, device=None, busaddr=None):
    if not product and not serial and not device and not busaddr:
        print("looking for product string: {}".format(DEFAULT_PRODUCT))
        product = DEFAULT_PRODUCT
    sdwire_dev = find_usb_device(
        product=product, serial=serial, device=device, busaddr=busaddr
    )
    if not sdwire_dev:
        print("SDWire device not found")
        return
    try:
        print(
            f"SDWire device found: {sdwire_dev.bus:03d}:{sdwire_dev.address:03d} | {sdwire_dev.idVendor:04x}:{sdwire_dev.idProduct:04x} | {usb.util.get_string(sdwire_dev, sdwire_dev.iProduct)} | {usb.util.get_string(sdwire_dev, sdwire_dev.iSerialNumber)}"
        )
    except Exception as e:
        print(
            f"SDWire device found: {sdwire_dev.bus:03d}:{sdwire_dev.address:03d} | {sdwire_dev.idVendor:04x}:{sdwire_dev.idProduct:04x}"
        )

    try:
        ftdi = Ftdi()
        ftdi.open_from_device(sdwire_dev)
    except Exception as e:
        print(f"Error opening FTDI device: {e}")
        return

    print(f"Set CBUS to 0x{0xF0 | target:02X}")
    try:
        ftdi.set_bitmode(0xF0 | target, Ftdi.BitMode.CBUS)
    except Exception as e:
        print(f"Error setting CBUS: {e}")

    ftdi.close()


def handle_cmd(args):
    if args.command == "list":
        usb_devices = list_usb_devices()
        print("busaddr |  device   | product | serial")
        for device in usb_devices:
            print(device)
    elif args.command == "attach":
        set_sdwire(
            0x01,
            product=args.product,
            serial=args.serial,
            device=args.device,
            busaddr=args.busaddr,
        )
    elif args.command == "detach":
        set_sdwire(
            0x00,
            product=args.product,
            serial=args.serial,
            device=args.device,
            busaddr=args.busaddr,
        )
    else:
        print(f"Unknown command: {args.command}")


def main():
    example_usage = """Example usage:
    python sdwire.py list
    python sdwire.py attach
    python sdwire.py attach --serial bdgrd_sdwirec_521
    python sdwire.py detach --device 04e8:6001

If no product, serial, device or busaddr is specified, the default product string "sd-wire" is used.
    """
    parser = argparse.ArgumentParser(
        description="SDWire control script",
        epilog=example_usage,
        formatter_class=argparse.RawDescriptionHelpFormatter,
    )
    parser.add_argument(
        "command",
        choices=["list", "attach", "detach"],
        help="List all USB devices or attach/detach SDWire",
    )
    parser.add_argument(
        "--product", type=str, help="Match the product string of the device"
    )
    parser.add_argument(
        "--serial", type=str, help="Match the serial number of the device"
    )
    parser.add_argument(
        "--device", type=str, help="Find by device's VendorID:ProductID"
    )
    parser.add_argument("--busaddr", type=str, help="Find by device's bus:address")
    args = parser.parse_args()
    handle_cmd(args)


if __name__ == "__main__":
    main()

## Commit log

2023-03-26 Rev 1.2
    [sdwirec.kicad_pcb, sdwirec.kicad_sch]
2023-07-17 Rev 1.3
    [sdwirec.kicad_pcb]
2023-07-17 squash! Rev 1.3
    [sdwirec.kicad_pcb]
2024-09-06 add schottky diode on vdd_device line
    [sdwirec.kicad_sch]
2024-09-06 squash! add schottky diode on vdd_device line
    [sdwirec.kicad_pcb, sdwirec.kicad_sch]
2024-10-14 sdwire-cli: fix usbbus detection #3
    [sdwire.py]
